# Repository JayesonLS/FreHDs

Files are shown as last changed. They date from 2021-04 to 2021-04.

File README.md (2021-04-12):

FreHDs
======

OriginalVecovenFiles
--------------------

An unmodified copy of Frederic Vecoven's 2.14 file release for
easy reference.

OriginalFreHDKiCad
------------------

Frederic Vecoven's original schematic transcribed into KiCard to 
use as a starting point for derivative projects. 

[Latest schematic PDF](OriginalFreHDKiCad/OriginalFreHDKiCad.pdf)

A PCB layout has also been created using the original gerbers. 
Note however that this was used for checking the correctness of the
schematic and is not intended for production. Some of the footprints
and clearances are very rough and should be corrected / cleaned up
before attempting to produce boards. Just use the original gerbers instead.

_Derivative projects may follow, time permitting._

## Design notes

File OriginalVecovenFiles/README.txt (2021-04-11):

TRS-HARD disk emulator, aka 'FreHD'
===================================

Current release: 2.14

TRS-HARD is my contribution to the TRS80 community. It emulates
genuine Tandy hard drives, with hard drive images stored on a FAT
filesystem, located on a SD-card.

Everything to build the emulator is contained in this archive,
organized in the following directories :

+ pcb
  - bom    : build material list, with Farnell part-numbers
  - gal    : equations of the GAL and the compiled jedec file
  - gerber : gerber files, ready to be sent to a PCB manufacture.
  - pdf    : schematics and pcb, in pdf format
  - protel : pcb source (schematics and pcb), in protel99 format

+ pic      : pic source code and compiled hex file.
  - FatFS  : elm FatFS library, ported to PIC18

+ z80
  - fredhd_rom : source code of the boot menu
  - fredhd_rom/rom-patches : patches for all TRS80 models
  - utils : FreHD utilities

To build the PIC software, you will need Microchip C18 compiler (free)
and MPLab (I used version 8.36). You will also need perl, which is
used to compute the CRC16 used by the bootloader. (If you modify the
source, you need to compile twice, the second time to include the
correct CRC in your hex file).

To build the Z80 code, you need zmac. We are using version 1.3, this
assembler is public domain (by Bruce Norskog and others).

To build the rom patches, you need 'asl'. It is available at:
http://john.ccac.rwth-aachen.de:8000/as/

This project started during the long evenings of December 2012, and I
am very proud to release it to the community today, May 12th 2013. 
Many thanks to Andrew Quinn, who beta-tested and motivated me to
finish this project, or at least make it usable :)

One last thing : you may modify, duplicate, enhance or do whatever you
want with the code. All I ask is to keep this README file. You must
make your modifications available (GPL). If you decide to build and
sell (modified) emulators, all I ask is an emulator for my TRS80, so I
can test your changes.

Enjoy !

-Frederic Vecoven (frederic@vecoven.com)

Last update: Thu Jan 23 15:19:26 2014

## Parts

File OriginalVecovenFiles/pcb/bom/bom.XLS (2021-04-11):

Part Type | Designator | Description | Farnell
1k | R3 | Resistor | 934-1102
1k | R1 | Resistor
1uF | C12 | Capacitor | 969-3734
1uF | C9 | Capacitor
1uF | C8 | Capacitor
1uF | C7 | Capacitor
1uF | C6 | Capacitor
3.3V | BAT1 | Battery Holder | 131-9749
4k7 | R17 | Resistor | 934-1951
4k7 | R16 | Resistor
4k7 | R15 | Resistor
10MHz | Y1 | Crystal | 161-1856
10k | R2 | Resistor | 934-1110
10k | R12 | Resistor
10k | R4 | Resistor
10k | R5 | Resistor
10k | R18 | Resistor
10u | C4 | Capacitor | 969-3548
10u | C11 | Capacitor
22p | C2 | Capacitor | ???
22p | C3 | Capacitor
32.768kHz | Y2 | Crystal | 165-2573
74HC595 | U6 | Shift register | 316-6028
74HCT245 | U3 | Bus driver | 380-714
100n | C5 | Capacitor | 121-6444
100n | C10 | Capacitor
100n | C1 | Capacitor
220 | R9 | Resistor | 934-1528
220 | R10 | Resistor
220 | R7 | Resistor
330 | R11 | Resistor | 934-1730
330 | R6 | Resistor
330 | R13 | Resistor
330 | R14 | Resistor
330 | R8 | Resistor
BS170 | Q1 | Mosfet | 101-7687
CON2 | J5 | Connector | power connector
CON5 | J6 | Connector | 175-6964
CON5 | J1 | Connector | not needed
CON50 | J3 | 50 pins header | 839-5985
DS1307 | U7 | DS1307 real time clock | 147-0445
GAL16V8 | U2 | Generic Array Logic | ebay
LED | D1 | green led | any
LED | D2 | red led | any
MAX232 | U5 | MAX232 | 147-0445
PIC18F4620 | U1 | micro controller | 121-2704
SDCARD | J2 | SD Card Connector | 176-4372
TS2950-3.3 | U4 | Voltage regulator LDO | 175-5063
socket 8 pins | 1 |  | 110-3844
socket 16 pins | 2 |  | 110-3846
socket 20 pins | 2 |  | 110-3848
socket 40 pins | 1 |  | 110-3841 | (order for 12 parts)

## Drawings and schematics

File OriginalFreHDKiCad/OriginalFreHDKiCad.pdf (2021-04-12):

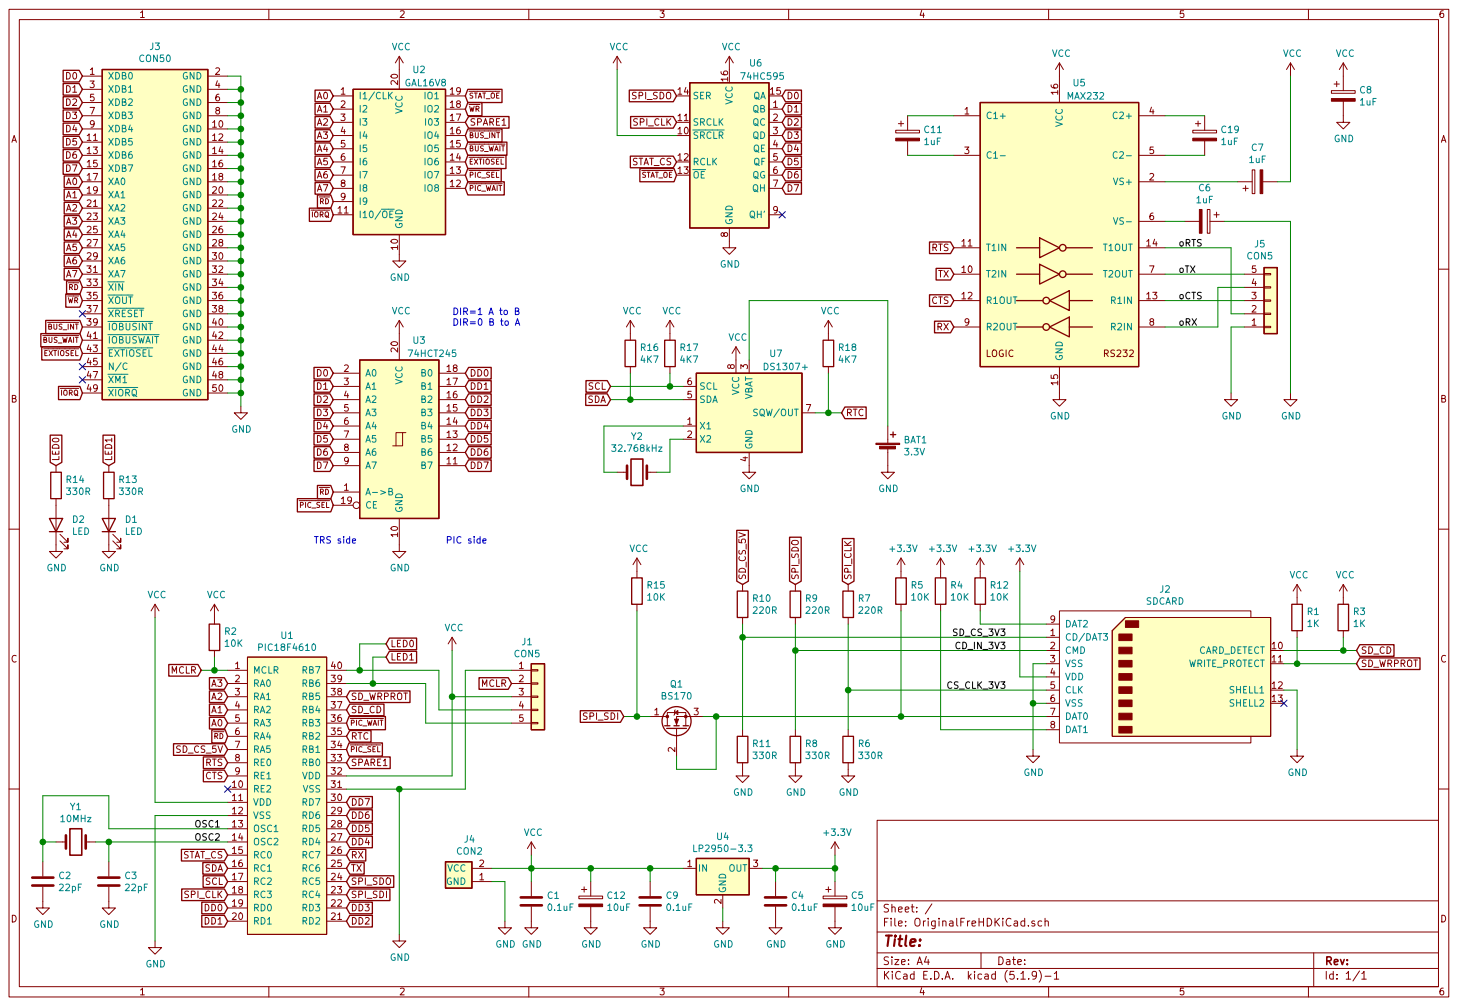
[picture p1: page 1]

DIR=1 A to B DIR=0 B to A

4 SDA 5 SCL 6 SQW/OUT 7 VCC

File: OriginalFreHDKiCad.sch Sheet: /
Id: 1/1 Title:

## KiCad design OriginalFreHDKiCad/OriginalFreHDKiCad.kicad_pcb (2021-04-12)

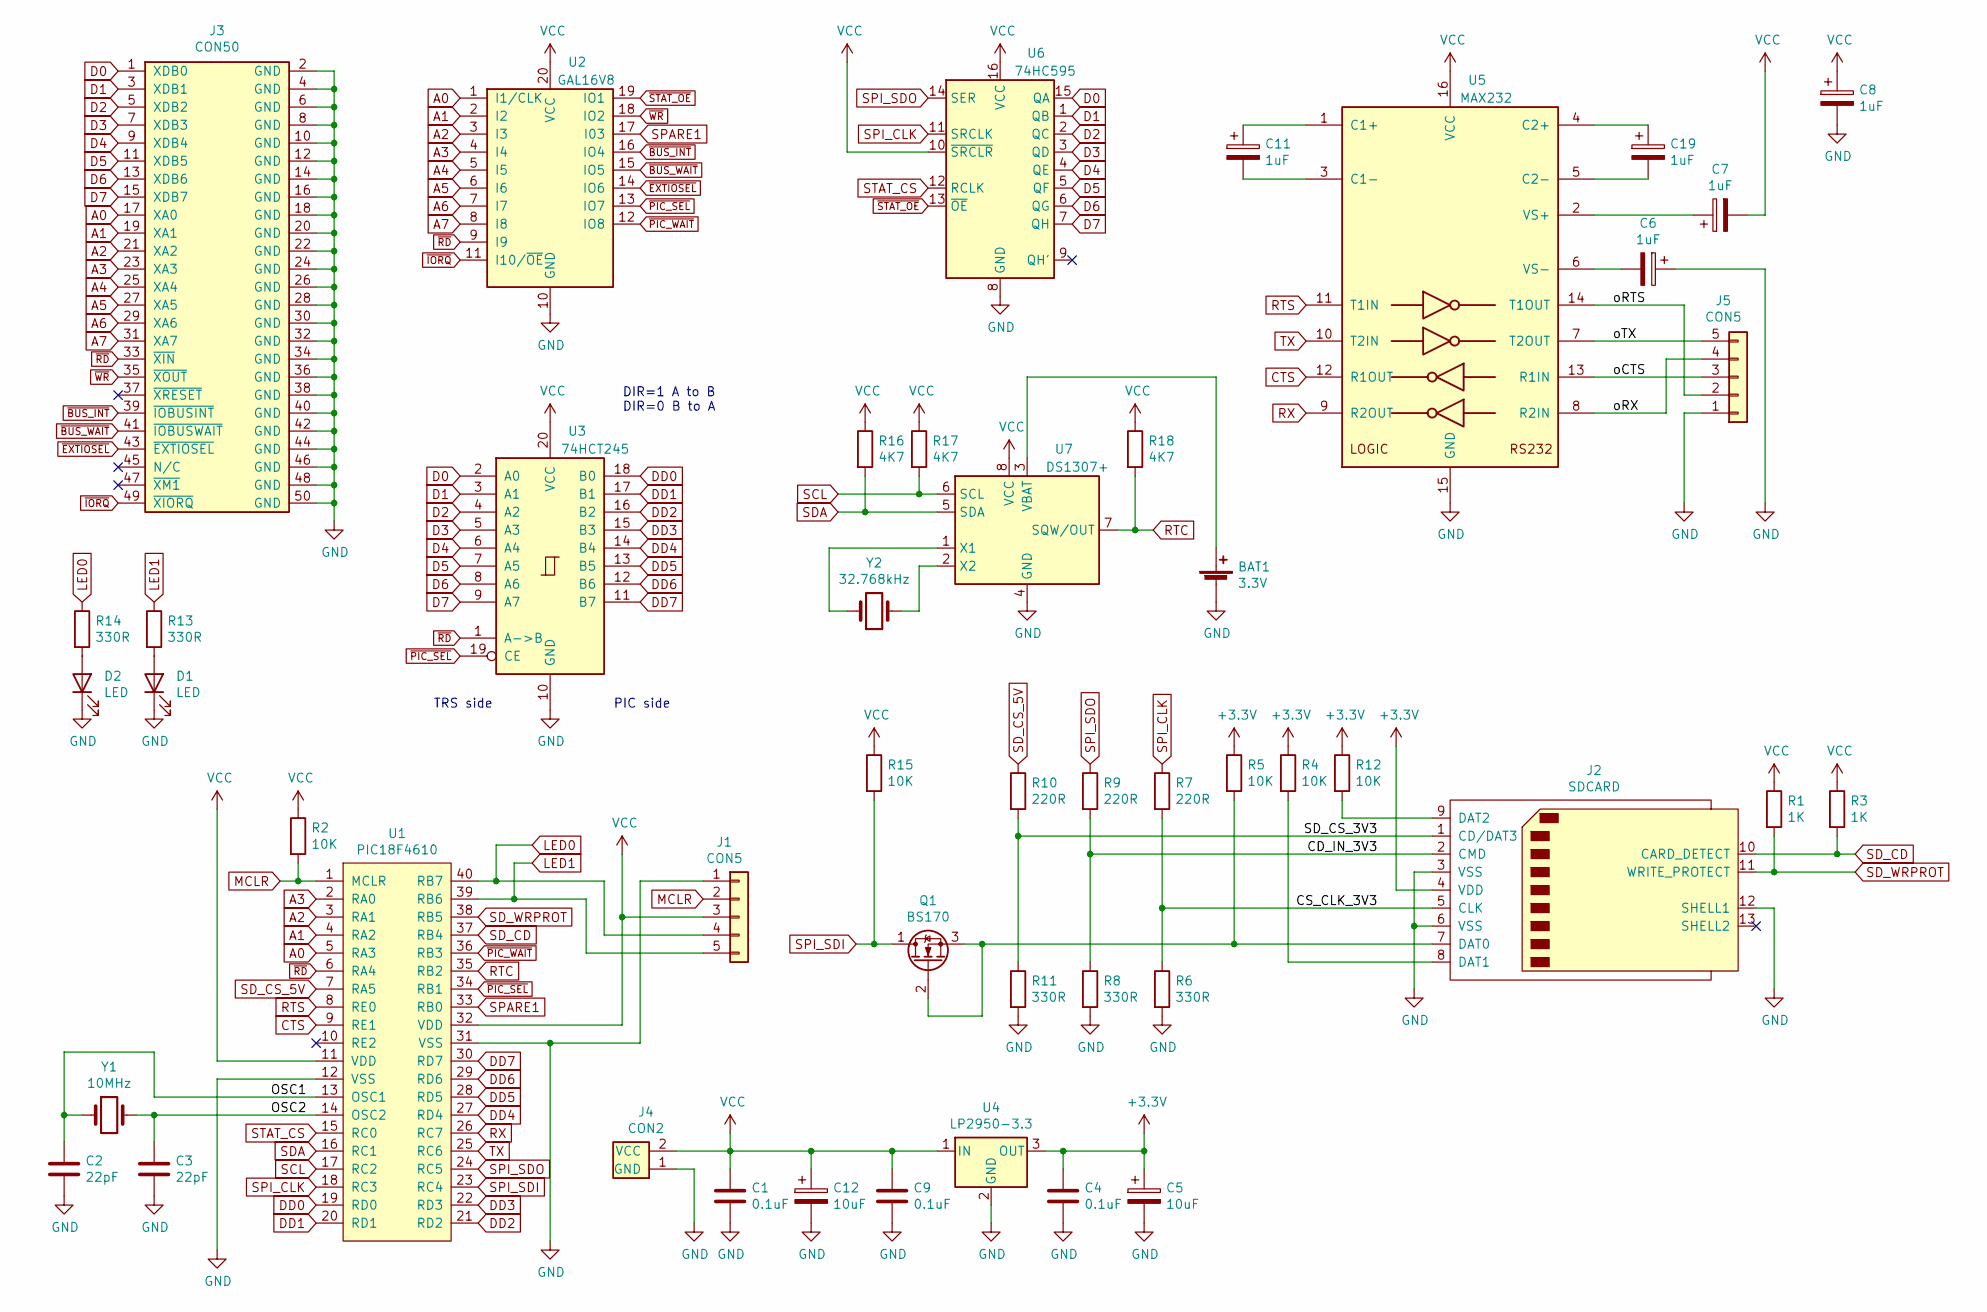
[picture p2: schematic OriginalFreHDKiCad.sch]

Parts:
BAT1: 3.3V; BatteryHolder_Keystone_1060_1x2032
C1, C4, C9: 0.1uF; C_Disc_D8.0mm_W2.5mm_P5.00mm
C2, C3: 22pF; C_Disc_D8.0mm_W2.5mm_P5.00mm
C5, C12: 10uF; CP_Radial_D7.5mm_P2.50mm
C6, C7, C8, C11, C19: 1uF; CP_Radial_D7.5mm_P2.50mm
D1, D2: LED; LED_D5.0mm
J1, J5: CON5; PinHeader_1x05_P2.54mm_Vertical
J2: SDCARD; SD_TE_2041021
J3: CON50; PinHeader_2x25_P2.54mm_Vertical
J4: CON2; PinHeader_2x01_P2.54mm_Vertical
Q1: BS170; TO-92
R1, R3: 1K; R_Axial_DIN0207_L6.3mm_D2.5mm_P10.16mm_Horizontal
R2, R4, R5, R12, R15: 10K; R_Axial_DIN0207_L6.3mm_D2.5mm_P10.16mm_Horizontal
R6, R8, R11, R13, R14: 330R; R_Axial_DIN0207_L6.3mm_D2.5mm_P10.16mm_Horizontal
R7, R9, R10: 220R; R_Axial_DIN0207_L6.3mm_D2.5mm_P10.16mm_Horizontal
R16, R17, R18: 4K7; R_Axial_DIN0207_L6.3mm_D2.5mm_P10.16mm_Horizontal
U1: PIC18F4610; DIP-40_W15.24mm
U2: GAL16V8; DIP-20_W7.62mm
U3: 74HCT245; DIP-20_W7.62mm
U4: LP2950-3.3; TO-92
U5: MAX232; DIP-16_W7.62mm
U6: 74HC595; DIP-16_W7.62mm
U7: DS1307+; DIP-8_W7.62mm
Y1: 10MHz; Crystal_HC50_Vertical
Y2: 32.768kHz; Crystal_C38-LF_D3.0mm_L8.0mm_Horizontal

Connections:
+3V3: C4.1, C5.1, J2.4 (VDD), R4.1, R5.1, R12.1, U4.3 (OUT)
/CD_IN_3V3: J2.2 (CMD), R8.1, R9.2
/CS_CLK_3V3: J2.5 (CLK), R6.1, R7.2
/OSC1: C2.1, U1.13 (OSC1), Y1.1
/OSC2: C3.1, U1.14 (OSC2), Y1.2
/SD_CS_3V3: J2.1 (CD/DAT3), R10.2, R11.1
/oCTS: J5.3, U5.13 (R1IN)
/oRTS: J5.2, U5.14 (T1OUT)
/oRX: J5.4, U5.8 (R2IN)
/oTX: J5.5, U5.7 (T2OUT)
A0: J3.17 (XA0), U1.5 (RA3), U2.1 (I1/CLK)
A1: J3.19 (XA1), U1.4 (RA2), U2.2 (I2)
A2: J3.21 (XA2), U1.3 (RA1), U2.3 (I3)
A3: J3.23 (XA3), U1.2 (RA0), U2.4 (I4)
A4: J3.25 (XA4), U2.5 (I5)
A5: J3.27 (XA5), U2.6 (I6)
A6: J3.29 (XA6), U2.7 (I7)
A7: J3.31 (XA7), U2.8 (I8)
CTS: U1.9 (RE1), U5.12 (R1OUT)
D0: J3.1 (XDB0), U3.2 (A0), U6.15 (QA)
D1: J3.3 (XDB1), U3.3 (A1), U6.1 (QB)
D2: J3.5 (XDB2), U3.4 (A2), U6.2 (QC)
D3: J3.7 (XDB3), U3.5 (A3), U6.3 (QD)
D4: J3.9 (XDB4), U3.6 (A4), U6.4 (QE)
D5: J3.11 (XDB5), U3.7 (A5), U6.5 (QF)
D6: J3.13 (XDB6), U3.8 (A6), U6.6 (QG)
D7: J3.15 (XDB7), U3.9 (A7), U6.7 (QH)
DD0: U1.19 (RD0), U3.18 (B0)
DD1: U1.20 (RD1), U3.17 (B1)
DD2: U1.21 (RD2), U3.16 (B2)
DD3: U1.22 (RD3), U3.15 (B3)
DD4: U1.27 (RD4), U3.14 (B4)
DD5: U1.28 (RD5), U3.13 (B5)
DD6: U1.29 (RD6), U3.12 (B6)
DD7: U1.30 (RD7), U3.11 (B7)
GND: BAT1.2 (-), C1.2, C2.2, C3.2, C4.2, C5.2, C6.1, C8.2, C9.2, C12.2, D1.1 (K), D2.1 (K), J1.1, J2.3 (VSS), J2.6 (VSS), J2.12 (SHELL1), J3.2 (GND), J3.4 (GND), J3.6 (GND), J3.8 (GND), J3.10 (GND), J3.12 (GND), J3.14 (GND), J3.16 (GND), J3.18 (GND), J3.20 (GND), J3.22 (GND), J3.24 (GND), J3.26 (GND), J3.28 (GND), J3.30 (GND), J3.32 (GND), J3.34 (GND), J3.36 (GND), J3.38 (GND), J3.40 (GND), J3.42 (GND), J3.44 (GND), J3.46 (GND), J3.48 (GND), J3.50 (GND), J4.1 (GND), J5.1, R6.2, R8.2, R11.2, U1.12 (VSS), U1.31 (VSS), U2.10 (GND), U3.10 (GND), U4.2 (GND), U5.15 (GND), U6.8 (GND), U7.4 (GND)
LED0: J1.4, R14.1, U1.40 (RB7)
LED1: J1.5, R13.1, U1.39 (RB6)
MCLR: J1.2, R2.2, U1.1 (MCLR)
unnamed: BAT1.1 (+), U7.3 (VBAT)
unnamed: C6.2, U5.6 (VS-)
unnamed: C7.1, U5.2 (VS+)
unnamed: C11.1, U5.1 (C1+)
unnamed: C11.2, U5.3 (C1-)
unnamed: C19.1, U5.4 (C2+)
unnamed: C19.2, U5.5 (C2-)
unnamed: D1.2 (A), R13.2
unnamed: D2.2 (A), R14.2
unnamed: J2.7 (DAT0), Q1.2 (G), Q1.3 (S), R5.2
unnamed: J2.8 (DAT1), R4.2
unnamed: J2.9 (DAT2), R12.2
unnamed: U7.1 (X1), Y2.1
unnamed: U7.2 (X2), Y2.2
RTC: R18.2, U1.35 (RB2), U7.7 (SQW/OUT)
RTS: U1.8 (RE0), U5.11 (T1IN)
RX: U1.26 (RC7), U5.9 (R2OUT)
SCL: R17.2, U1.17 (RC2), U7.6 (SCL)
SDA: R16.2, U1.16 (RC1), U7.5 (SDA)
SD_CD: J2.10 (CARD_DETECT), R3.2, U1.37 (RB4)
SD_CS_5V: R10.1, U1.7 (RA5)
SD_WRPROT: J2.11 (WRITE_PROTECT), R1.2, U1.38 (RB5)
SPARE1: U1.33 (RB0), U2.17 (I03)
SPI_CLK: R7.1, U1.18 (RC3), U6.11 (SRCLK)
SPI_SDI: Q1.1 (D), R15.2, U1.23 (RC4)
SPI_SDO: R9.1, U1.24 (RC5), U6.14 (SER)
STAT_CS: U1.15 (RC0), U6.12 (RCLK)
TX: U1.25 (RC6), U5.10 (T2IN)
VCC: C1.1, C7.2, C8.1, C9.1, C12.1, J1.3, J4.2 (VCC), R1.1, R2.1, R3.1, R15.1, R16.1, R17.1, R18.1, U1.11 (VDD), U1.32 (VDD), U2.20 (VCC), U3.20 (VCC), U4.1 (IN), U5.16 (VCC), U6.10 (~SRCLR), U6.16 (VCC), U7.8 (VCC)
~BUS_INT: J3.39 (~IOBUSINT), U2.16 (IO4)
~BUS_WAIT: J3.41 (~IOBUSWAIT), U2.15 (IO5)
~EXTIOSEL: J3.43 (~EXTIOSEL), U2.14 (IO6)
~IORQ: J3.49 (~XIORQ), U2.11 (I10/~OE~)
~PIC_SEL: U1.34 (RB1), U2.13 (IO7), U3.19 (CE)
~PIC_WAIT: U1.36 (RB3), U2.12 (IO8)
~RD: J3.33 (~XIN), U1.6 (RA4), U2.9 (I9), U3.1 (A->B)
~STAT_OE: U2.19 (IO1), U6.13 (~OE)
~WR: J3.35 (~XOUT), U2.18 (IO2)

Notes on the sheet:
TRS side
PIC side
DIR=1 A to B DIR=0 B to A

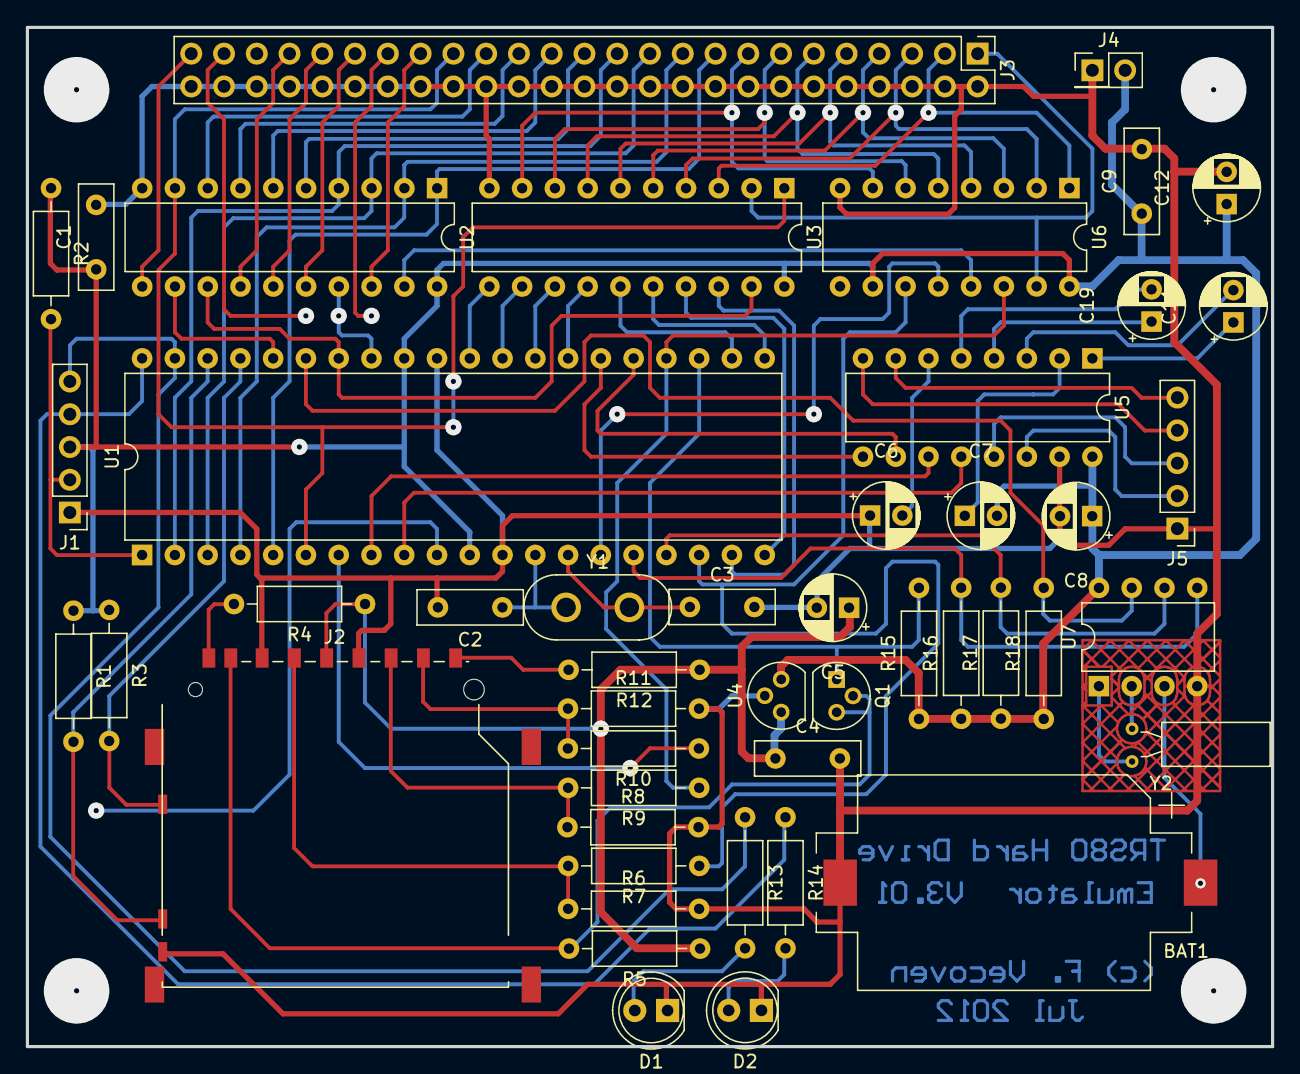
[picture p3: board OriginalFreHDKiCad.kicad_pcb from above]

Board: 2 copper layers, 96.5 x 79.0 mm, 48 parts (0 on the bottom side), 77 nets.

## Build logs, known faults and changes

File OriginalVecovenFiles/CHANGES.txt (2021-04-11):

2.14 - latest version (Thu Jan 23 17:07:06 2014)
+ all latest enhancements
+ support for Kaypro

2.02 - bug fixes (Mon May 20 10:07:52 2013)
+ fixed a bug which prevented "fast seek" from being active. (big
  performance boost)
+ PCB: BS170 "polarity" may be wrong on the PCB silk screen. Double
  check with the datasheets of our BS170, but chances are that you
  need to mount it opposed to the silk screen drawing.
+ updated vhdutl/cmd

2.01 - internal release, not distributed

2.00 - initial release

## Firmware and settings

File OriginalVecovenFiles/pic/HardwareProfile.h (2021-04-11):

/*
 * Copyright (C) 2013 Frederic Vecoven
 *
 * This file is part of trs_hard
 *
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
 * You should have received a copy of the GNU General Public License
 * along with this program. If not, see <http://www.gnu.org/licenses/>.
 */

#ifndef HARDWARE_PROFILE_H
#define HARDWARE_PROFILE_H
	
#include <p18f4620.h>
	
/** CLOCK FREQUENCY ********************************************/
#define GetSystemClock()		(40000000ul)      // Hz
#define GetInstructionClock()	(GetSystemClock()/4)
#define GetPeripheralClock()	GetInstructionClock()
   
/** I/O pin definitions ****************************************/
#define INPUT_PIN 		1
#define OUTPUT_PIN 		0    

/* SD CARD */
#define SD_CS			LATAbits.LATA5		// SD chip select
#define SD_CS_TRIS		TRISAbits.TRISA5	// SD chip select TRIS
#define SPI_SCK_TRIS	TRISCbits.TRISC3	// SPI Clock TRIS
#define SPI_MISO_TRIS	TRISCbits.TRISC4	// SPI Master input/Slave output TRIS
#define SPI_MOSI_TRIS	TRISCbits.TRISC5	// SPI Master output/Slave input TRIS
/*
 * Card write-protect and card detect must be on the same port.
 * If not, adapt diskio.c
 */
#define SD_WP			PORTBbits.RB5		// Card Write Protect
#define SD_WP_TRIS		TRISBbits.TRISB5	// Card Write Protect TRIS
#define SD_WP_PIN		5
#define SD_CD			PORTBbits.RB4		// Card Detect
#define SD_CD_TRIS		TRISBbits.TRISB4	// Card Detect TRIS
#define SD_CD_PIN		4
#define SD_WP_CD_PORT	PORTB

/* STATUS REGISTER */
#define STAT_CS			LATCbits.LATC0		// STATUS LOAD
#define STAT_CS_TRIS	TRISCbits.TRISC0
   
/* TRS80 signals */
#define TRS_ADDR		PORTA				// low nibble is A[3..0] reversed!  RW is bit 4
#define TRS_ADDR_TRIS	TRISA
#define TRS_DATA_IN		PORTD
#define TRS_DATA_OUT	LATD
#define TRS_DATA_TRIS	TRISD
#define TRS_RD_N		PORTAbits.RA4		// 0=read 1=write
#define TRS_RD_N_TRIS	TRISAbits.TRISA4
#define TRS_WAIT		LATBbits.LATB3
#define TRS_WAIT_TRIS	TRISBbits.TRISB3
#define GAL_INT_IE		INTCON3bits.INT1IE
#define GAL_INT_IP		INTCON3bits.INT1IP
#define GAL_INT_IF		INTCON3bits.INT1IF
#define GAL_INT_EDGE	INTCON2bits.INTEDG1
#define GAL_INT_TRIS	TRISBbits.TRISB1
#define GAL_INT			PORTBbits.RB1

/* DS1307 RTC */
#define SDA_LAT			LATCbits.LATC1
#define SDA_PIN			PORTCbits.RC1
#define SDA_TRIS		TRISCbits.TRISC1
#define SCL_LAT			LATCbits.LATC2
#define SCL_PIN			PORTCbits.RC2
#define SCL_TRIS		TRISCbits.TRISC2
#define RTC_INT_IE		INTCON3bits.INT2IE
#define RTC_INT_IP		INTCON3bits.INT2IP
#define RTC_INT_IF		INTCON3bits.INT2IF
#define RTC_INT_EDGE	INTCON2bits.INTEDG2
#define RTC_INT_TRIS	TRISBbits.TRISB2
#define RTC_INT			PORTBbits.RB2

/* Serial Port */
#define TX_TRIS			TRISCbits.TRISC6
#define RX_TRIS			TRISCbits.TRISC7
#define RTS_TRIS		TRISEbits.TRISE0
#define RTS_LAT			LATEbits.LATE0
#define RTS_PIN			PORTEbits.RE0
#define CTS_TRIS		TRISEbits.TRISE1
#define CTS_LAT			LATEbits.LATE1
#define CTS_PIN			PORTEbits.RE1

/* LEDs */
#define GLED			LATBbits.LATB7		// green LED 
#define GLED_TRIS		TRISBbits.TRISB7	// green LED TRIS
#define RLED			LATBbits.LATB6		// red LED
#define RLED_TRIS		TRISBbits.TRISB6	// red LED TRIS

typedef enum {
	LED_OFF,
	LED_ON,
	LED_FAST_BLINK,
	LED_SLOW_BLINK
} led_state_t;
	

/* Spare pins */
#define SPARE1_TRIS		TRISBbits.TRISB0
#define SPARE2_TRIS		TRISEbits.TRISE2

/** USART SETTINGS *********************************************/
#define BAUD_RATE 57600

#endif

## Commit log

2021-04-11 Add original FreHD source files from Frederic Vecoven's web site.
    [bom.XLS, simul.DSN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]
2021-04-11 Initial pass at entering orignal FreHD schematic into KiCad.
    [OriginalFreHDKiCad.kicad_pcb, OriginalFreHDKiCad.sch]
2021-04-11 Initial import of original gerbers into pcbnew.
    [OriginalFreHDKiCad.kicad_pcb]
2021-04-11 WIP on matching scheamtic to imported gerbers.
    [OriginalFreHDKiCad.kicad_pcb, OriginalFreHDKiCad.sch]
2021-04-12 Finish matching schematic to imported gerbers - the process found one small error.
    [OriginalFreHDKiCad.kicad_pcb, OriginalFreHDKiCad.sch]
2021-04-12 Add PDF of schematic.

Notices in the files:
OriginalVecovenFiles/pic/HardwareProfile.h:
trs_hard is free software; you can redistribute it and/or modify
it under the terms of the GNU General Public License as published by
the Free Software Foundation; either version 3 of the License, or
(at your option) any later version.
